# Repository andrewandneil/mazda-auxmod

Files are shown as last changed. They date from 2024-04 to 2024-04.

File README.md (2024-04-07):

# Mazda AuxMod

An effort to recreate the classic AuxMod for Mazda Radios from around 2000-2007 using code & PCB designs from NikoSapi's MazdaSpoof. 

Currently supports iPod controls from NikoSapi's design, and an Aux input. (CURRENTLY UNTESTED)

## Links

- The Original AuxMod: [sylfex.com](https://www.sylfex.com/products/AuxMod/)
- NikoSapi's MazdaSpoof: [nikosapi.org](https://nikosapi.org/w/index.php/MazdaSpoof_-_A_Tape_Deck_Emulator)

## Goals

- Produce something similar to the original AuxMod and NikoSapi's MazdaSpoof. 
- Design a simple connector (using 2 PCBs seperated by standoffs) to allow easy push-fit connection to the Radio with zero modification.

## TODO:

- [ ] Test circuit
- [ ] Design alternate way of connection for plugging into TAPE/MD port on radio
- [ ] Rewrite portions of code
- [ ] Native BlueTooth integration (skipping tracks etc)

## License

Uses code from NikoSapi, shared under GPLv3.

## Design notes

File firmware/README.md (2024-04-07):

# Firmware

`This tutorial is a work in progress!!`

### Instructions:

1. Open this 'firmware' folder in Visual Studio Code (or VSCodium!!). 
2. Ensure you have PlatformIO installed.
3. Build this firmware using the checkmark located at the bottom of the screen.
4. Flash the firmware to the ATtiny45 using the upload button (the right arrow).
5. Insert the ATtiny45 into the socket on the AuxMod.

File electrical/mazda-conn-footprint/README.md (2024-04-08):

# Mazda Radio Connector

Find here a KiCad Footprint for the Mazda Radio Connector.

Untested, however measurements checkout.

Last updated 08/04/24.

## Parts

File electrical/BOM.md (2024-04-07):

# Bill of Materials for Mazda AuxMod (Rev 1.0)

## Universal (AUX jack or iPod):
- R1 - 1K
- R17 - 10K
- R18 - 10K

- C1 - 0.33uF
- C2 - 0.01uF

- U1 - ATtiny45
- U2 - 78L05

- Q1 - 2n3904

- J1 - Mazda Radio Connector

## In Addition:

### Only Aux In:
- J3 - PJ-320D

### Only iPod Integration:
- R2 - 68K
- R3 - 33K
- R4 - 2K
- R5 - 3.9K
- R6 - 10K
- R7 - 1K
- R8 - 10K
- R9 - 100K
- R10 - 22K
- R11 - 22K
- R12 - 27K
- R13 - 33K
- R14 - 22K
- R15 - 33K
- R16 - 68K

- C3 - 0.1uF
- C4 - 0.33uF
- C5 - 10uF

- U3 - L7805

- Q2 - 2n3904
- Q3 - 2sa715 or 2sb744

- J2 - 2x5 2.54mm Pin Header

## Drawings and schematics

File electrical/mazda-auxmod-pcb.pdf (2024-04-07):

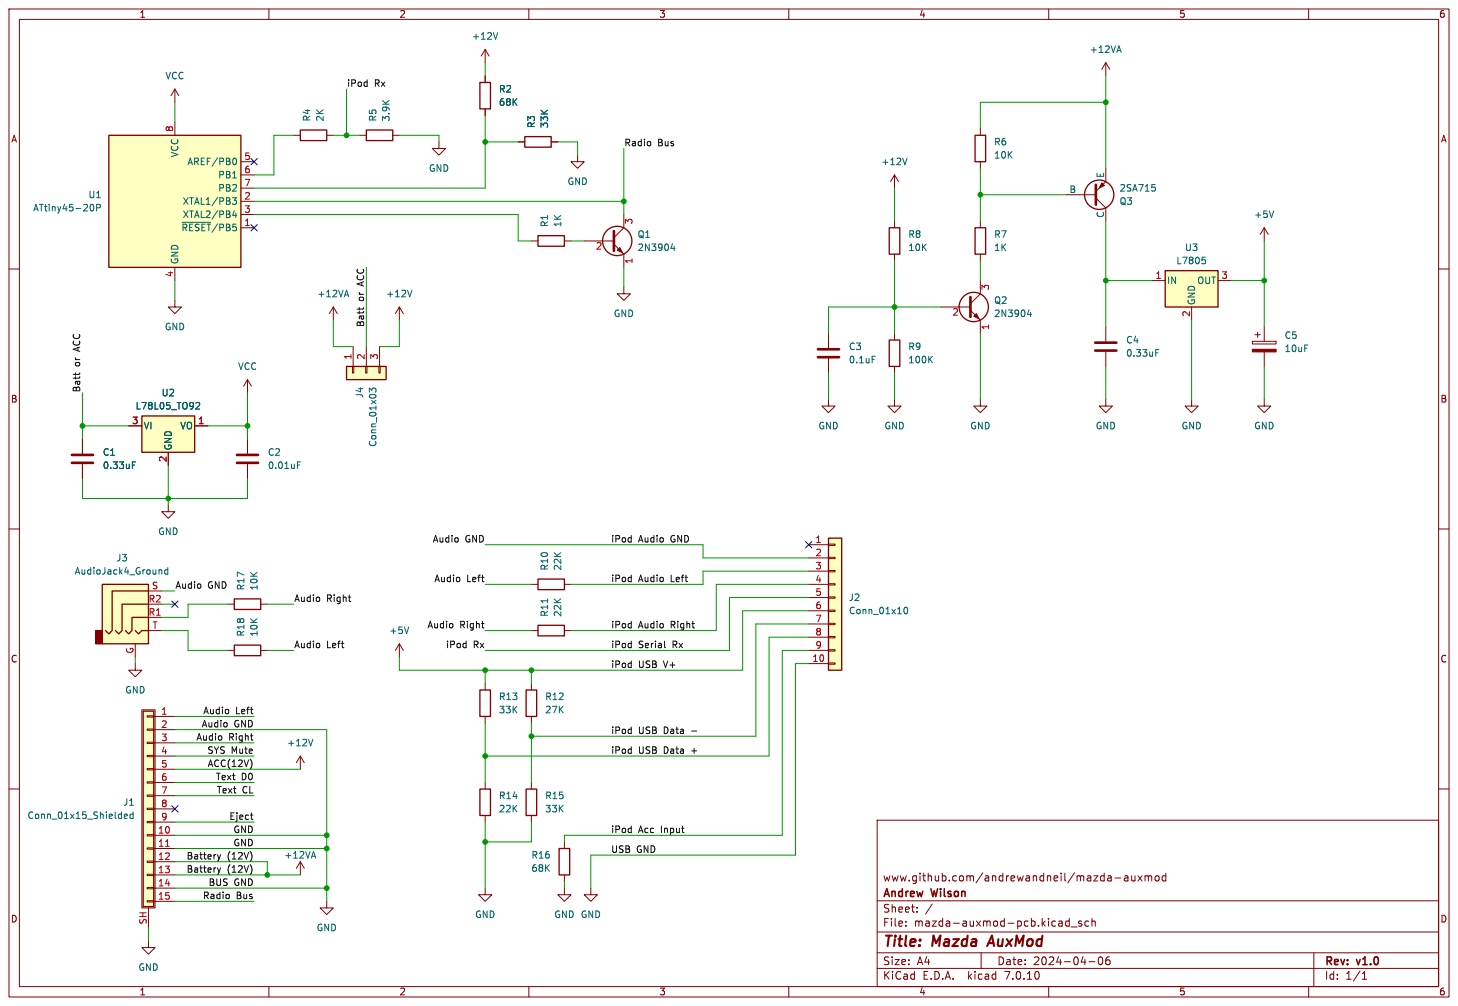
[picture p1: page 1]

Audio GND Batt or ACC

iPod Rx Audio GND

Audio Left Audio Right SYS Mute
Audio GND
iPod USB Data - Text CL ACC(12V)

File: mazda-auxmod-pcb.kicad_sch Sheet: / Andrew Wilson www.github.com/andrewandneil/mazda-auxmod

Id: 1/1 Title: Mazda AuxMod

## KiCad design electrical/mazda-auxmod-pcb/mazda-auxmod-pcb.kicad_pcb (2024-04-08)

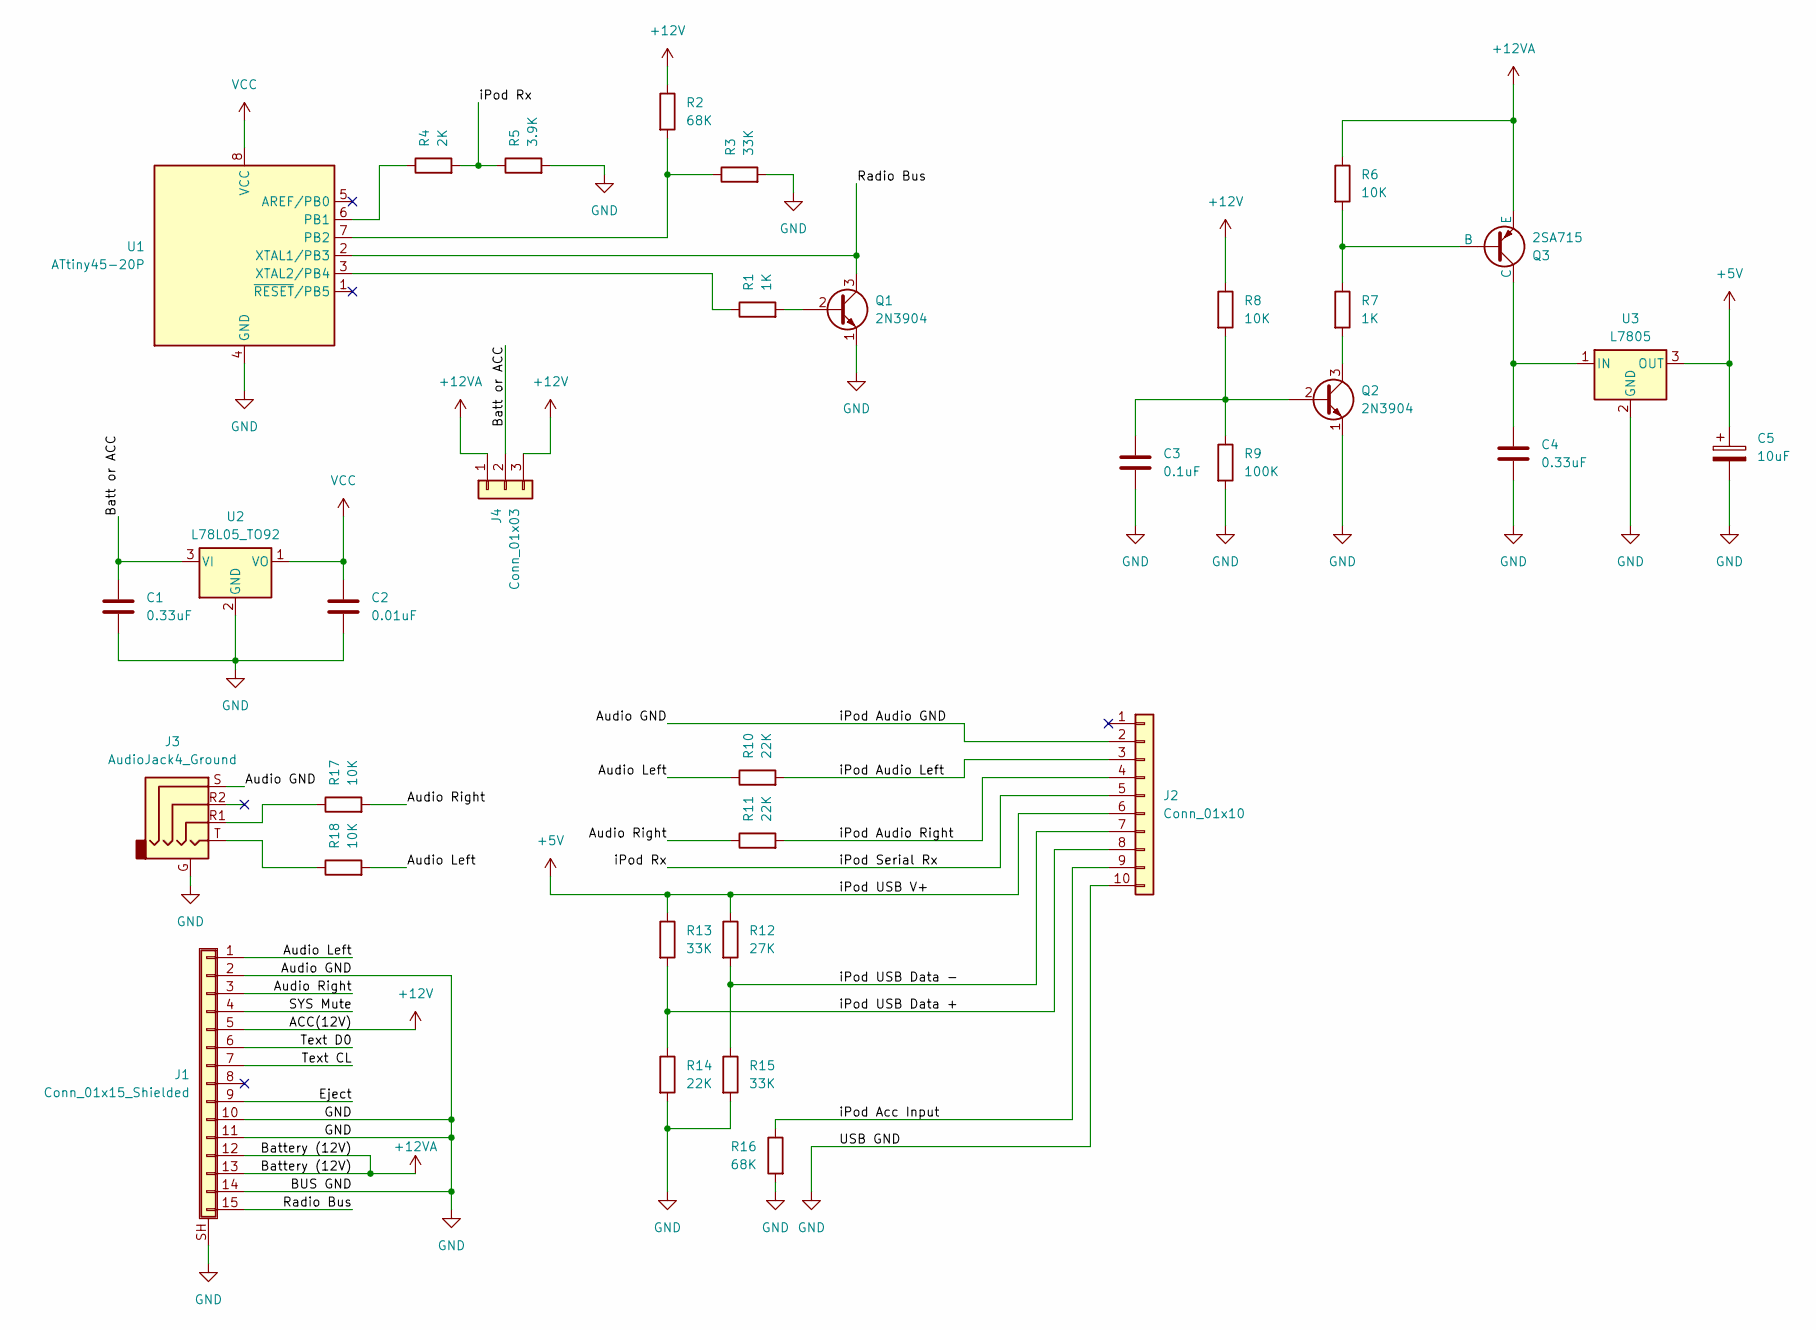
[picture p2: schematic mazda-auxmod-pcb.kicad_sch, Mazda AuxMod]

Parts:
C1, C4: 0.33uF; C_Disc_D5.0mm_W2.5mm_P2.50mm
C2: 0.01uF; C_Disc_D5.0mm_W2.5mm_P2.50mm
C3: 0.1uF; C_Disc_D5.0mm_W2.5mm_P2.50mm
C5: 10uF; CP_Radial_D5.0mm_P2.00mm
J1: Conn_01x15_Shielded; Mazda_Radio_Connector
J2: Conn_01x10; PinHeader_2x05_P2.54mm_Vertical
J3: AudioJack4_Ground; Jack_3.5mm_PJ320D_Horizontal
J4: Conn_01x03; SolderJumper-3_P1.3mm_Bridged2Bar12_RoundedPad1.0x1.5mm
Q1, Q2: 2N3904; TO-92_Inline
Q3: 2SA715; TO-126-3_Horizontal_TabDown
R1, R7: 1K; R_Axial_DIN0204_L3.6mm_D1.6mm_P7.62mm_Horizontal
R2, R16: 68K; R_Axial_DIN0204_L3.6mm_D1.6mm_P7.62mm_Horizontal
R3, R13, R15: 33K; R_Axial_DIN0204_L3.6mm_D1.6mm_P7.62mm_Horizontal
R4: 2K; R_Axial_DIN0204_L3.6mm_D1.6mm_P7.62mm_Horizontal
R5: 3.9K; R_Axial_DIN0204_L3.6mm_D1.6mm_P7.62mm_Horizontal
R6, R8, R17, R18: 10K; R_Axial_DIN0204_L3.6mm_D1.6mm_P7.62mm_Horizontal
R9: 100K; R_Axial_DIN0204_L3.6mm_D1.6mm_P7.62mm_Horizontal
R10, R11, R14: 22K; R_Axial_DIN0204_L3.6mm_D1.6mm_P7.62mm_Horizontal
R12: 27K; R_Axial_DIN0204_L3.6mm_D1.6mm_P7.62mm_Horizontal
U1: ATtiny45-20P; DIP-8_W7.62mm
U2: L78L05_TO92; TO-92_Inline
U3: L7805; TO-220-3_Horizontal_TabDown

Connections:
+5V: C5.1, J2.6, R12.1, R13.1, U3.3 (OUT)
+12V: J1.5, J4.3, R2.1, R8.1
+12VA: J1.12, J1.13, J4.1, Q3.3 (E), R6.1
/Audio Left: J1.1, R10.1, R18.2
/Audio Right: J1.3, R11.1, R17.2
/Batt or ACC: C1.1, J4.2, U2.3 (VI)
/Eject: J1.9
/Radio Bus: J1.15, Q1.3 (C), U1.2 (XTAL1/PB3)
/SYS Mute: J1.4
/Text CL: J1.7
/Text D0: J1.6
/iPod Acc Input: J2.9, R16.1
/iPod Audio Left: J2.3, R10.2
/iPod Audio Right: J2.4, R11.2
/iPod Rx: J2.5, R4.2, R5.1
/iPod USB Data +: J2.8, R13.2, R14.1
/iPod USB Data -: J2.7, R12.2, R15.1
GND: C1.2, C2.2, C3.2, C4.2, C5.2, J1.2, J1.10, J1.11, J1.14, J1.SH (Shield), J2.2, J2.10, J3.G, J3.S, Q1.1 (E), Q2.1 (E), R3.2, R5.2, R9.2, R14.2, R15.2, R16.2, U1.4 (GND), U2.2 (GND), U3.2 (GND)
unnamed: J3.R1, R17.1
unnamed: J3.T, R18.1
unnamed: Q1.2 (B), R1.2
unnamed: C3.1, Q2.2 (B), R8.2, R9.1
unnamed: Q2.3 (C), R7.2
unnamed: Q3.2 (B), R6.2, R7.1
unnamed: C4.1, Q3.1 (C), U3.1 (IN)
unnamed: R4.1, U1.6 (PB1)
unnamed: R2.2, R3.1, U1.7 (PB2)
unnamed: R1.1, U1.3 (XTAL2/PB4)
VCC: C2.1, U1.8 (VCC), U2.1 (VO)

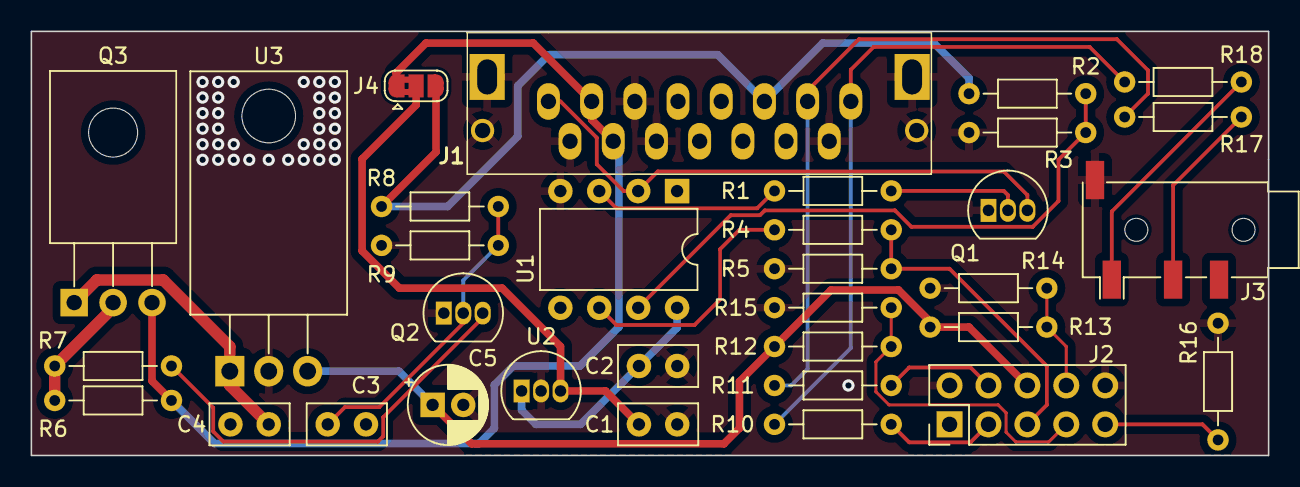
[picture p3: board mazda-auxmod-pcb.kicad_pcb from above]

Board: 2 copper layers, 80.8 x 27.7 mm, 33 parts (0 on the bottom side), 25 nets.

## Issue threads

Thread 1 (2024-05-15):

How can I test this project?

613B, 2024-05-15:
Hi !

First of all, I'm impressed with this project. This is exactly what I was looking for.
I have knowledge of embedded circuit design, firmware programming, simple artwork design for PCB. So, I would like to build this project and run it in my environment.

So, I would like you to ask a question, how are you testing this project?
Probably I can build this project, but its installation is so complex and hard for me.
Do I have to take out the audio deck every time? Please let me know if there is a simple test method. My car is Mazda RX-8 (2004).

thank you.

andrewandneil, 2024-05-15:
I own a 2006 RX-8, but have two spare radios from the cars that I've setup on my bench. In order to connect it you currently need a connector taken from an old radio that connects the main circuit board to the CD changer. If you have that you just solder it to the board and it should be plug and play, other than soldering the components to the board. No modification should be necessary to the car, but I think to install it you'll need to remove the radio from the car. I haven't really tested this, but I've had very basic functions working on the bench.
At the moment I've got Uni exams so this project has taken a bit of a back burner, but I'll see about adding some photos of the connector to the project in the next couple days.
If you don't have or don't want to remove a connector from an old radio, you can always solder the wires directly to the connector like NikoSapi did in his implementation.

613B, 2024-05-28:
Thank you. I'll try it.

I'm sure I'll have questions about the test, so I'll leave this issue open. note that.

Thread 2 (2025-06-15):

How to get the connector

jhahvhi, 2025-06-15:
Hello.
I'd like to implement this project myself, adding things like Bluetooth. The problem I'm having is that I can't find the necessary connector online. Do you know where I can get it?

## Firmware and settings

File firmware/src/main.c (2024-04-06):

/* spoof.c - Some software that pretends to be a tape deck for a Mazda head
             unit. It also interprets button presses on the head unit and can
             transmit them to an iPod.

    This code was written for an atmel ATtiny45.
*/

#include <avr/io.h>
#include <avr/interrupt.h>
#include <avr/pgmspace.h> 
#include <util/delay.h>

#include "commands.h"
#include "ipod.h"

// Pin definitions
#define INPUT_PIN       PB4 // pin that's connected to the radio's data bus
#define OUTPUT_PIN      PB3 // pin that controls a transistor which grounds the bus
#define POWER_SENSE PB2 // pin that's connected to ACC

// The receive buffer for commands from the HU
volatile uint8_t buffer[buffer_size];
volatile uint8_t buffer_pos = 0;
volatile uint8_t byte_pos = 0;

// A counter for to tell how many times the timer has ovrerflowed
volatile uint8_t command_delay = 0;

// A buffer to keep track of the previous playback control command
volatile uint8_t control_buffer = 0;


#define _PR pgm_read_byte
// Send a message on the Mazda radio bus
void send_message(radio_command *message)
{
    for (uint8_t nibble = 0; nibble < _PR(&message->length); nibble++){
        uint8_t n_message = _PR(&message->command[nibble/2]) >> 4*((nibble+1)%2);
        
        for (int8_t i = 3; i >= 0 ; i--){
            PORTB |= _BV(OUTPUT_PIN); // Pull the bus down
            if (n_message & _BV(i)) _delay_us(1700);
            else                    _delay_us(500);
            
            PORTB &= ~_BV(OUTPUT_PIN); // Release the bus
            if (n_message & _BV(i)) _delay_us(1300);
            else                    _delay_us(2500);
        }
    }
}

void parse_radio_message()
{
    // Anyone home?
    if (buffer[0] == 0x08){
        send_message(&TAPE_power_on);
        _delay_ms(8);
        send_message(&TAPE_cassette_present);
    }
    
    // Wake up!
    if (buffer[0] == 0x09){
        send_message(&TAPE_cassette_present);
        _delay_ms(10);
        send_message(&TAPE_stopped);
    }
    
    // Control command
    if (buffer[0] == 0x01){
        
        // Extract the specific subcommand and command
        uint8_t subcommand = buffer[1] >> 4;
        uint8_t command = (buffer[1] << 4) | (buffer[2] >> 4);
        
        // Playback control
        if (subcommand == 0x1){
            uint8_t command_diff = command ^ control_buffer;
            control_buffer = command;
            
            if (command_diff & PLAY)
                on_play_changed( command );
            
            if (command_diff & FASTFORWARD)
                on_fastforward_changed( command );
            
            if (command_diff & REWIND)
                on_rewind_changed( command );
            
            if (command_diff & STOP)
                on_stop_changed( command );
        }
        
        // Set configuration data
        if (subcommand == 0x4){
            if (command == 0)   
                on_repeat_changed( command );
            
            if (command & REPEAT)
                on_repeat_changed( command );
            
            if (command & RANDOM)
                on_random_pressed();
            
            if (command & SEEK_UP)
                on_seek_up_pressed();
            
            if (command & SEEK_DOWN)
                on_seek_down_pressed();
        }
    }
}

int main()
{
    // 8 bit timer (prescaler = 64)
    TCCR0A = _BV(WGM01);
    TCCR0B = _BV(CS01) | _BV(CS00);
    OCR0A = 117; // Trigger an interrupt every ~7.5ms
    TIMSK = _BV(OCIE0A);    
    
    // Interrupt on pin change (both types)
    GIMSK = _BV(PCIE) | _BV(INT0);
    PCMSK = _BV(PCINT4); // We want pin 3 (PB4)
    MCUCR = _BV(ISC00); // Trigger INT0 on any change
    
    // Set up the output pin
    DDRB = _BV(OUTPUT_PIN);
    
    // Set the ipod output pin
    ipod_enable_port();
    
    // Enable interrupts
    sei();
    
    // Do nothing, everything is handled by interrupts
    while(1);
    return 0;
}

// Pin change interrupt
ISR(PCINT0_vect)
{
    uint8_t elapsed_time = TCNT0;  // Store the timer value
    uint8_t pin = PINB & _BV(INPUT_PIN); // Store the pin value
    
    // If the bus is pulled to ground, a bit is starting to be transmitted
    // so the timer is reset and we can return while we wait for the 
    // bus to be pulled back to 5V.
    if (!pin){
        TCNT0 = 0;
        return;
    }
    
    // A logical 1 is when the bus is held low for ~1.7ms so we accept
    // anything from ~1.4ms to ~2ms as a logical 1.
    if (elapsed_time > 22 && elapsed_time < 32)
        buffer[buffer_pos] |= 1<<(7-byte_pos);
    
    // Anything else is assumed to be a 0, increase the byte position
    byte_pos++;
    
    // We've filled up a byte, move to the next one
    if (byte_pos > 7){
        byte_pos = 0;
        buffer_pos++;
        buffer[buffer_pos] = 0; // very important, clear the old value
    }
}

// Timer compare match interrupt
ISR(TIMER0_COMPA_vect)
{
    if (!buffer_pos){
        // clean up any bits that have been stored because of noise
        // (very useful on startup)
        byte_pos = 0;
        buffer[0] = 0;
        return;
    }
    
    // Wait one overflow to ensure that the bus is quiet
    if (command_delay == 0){
        command_delay++;
        return;
    }
    
    // The message is intended for the tape deck
    if ((buffer[0] & 0xf0) == 0x00)
        parse_radio_message();
    
    buffer_pos = 0;
    byte_pos = 0;
    buffer[0] = 0;
    command_delay = 0;
}

// Pin change interrupt to detect when accessory power has been cut
ISR(INT0_vect)
{
    if (PINB & _BV(PB2)){ // power is on
        ipod_enable_port();
        first_play = 1;
    } else {
        ipod_off();
        ipod_disable_port(); // save some power
    }
}

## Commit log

2024-04-06 inital file structure
    [mazda-auxmod-pcb.kicad_pcb, mazda-auxmod-pcb.kicad_sch]
2024-04-06 PCB Rev 1.0
    [mazda-auxmod-pcb.kicad_pcb, mazda-auxmod-pcb.kicad_sch]
2024-04-07 Added Schematic PDF
    [mazda-auxmod-pcb.kicad_sch]
2024-04-07 added BOM text file placeholder
2024-04-07 neatened up schematic/pcb
    [mazda-auxmod-pcb.kicad_pcb]
2024-04-07 added gerber files for rev 1.0
2024-04-07 changed BOM from txt to md
2024-04-07 updated BOM, changed formatting
2024-04-08 fixed footprint for radio connector
    [mazda-auxmod-pcb.kicad_pcb]
2024-04-08 added version info to pcb
    [mazda-auxmod-pcb.kicad_pcb]
